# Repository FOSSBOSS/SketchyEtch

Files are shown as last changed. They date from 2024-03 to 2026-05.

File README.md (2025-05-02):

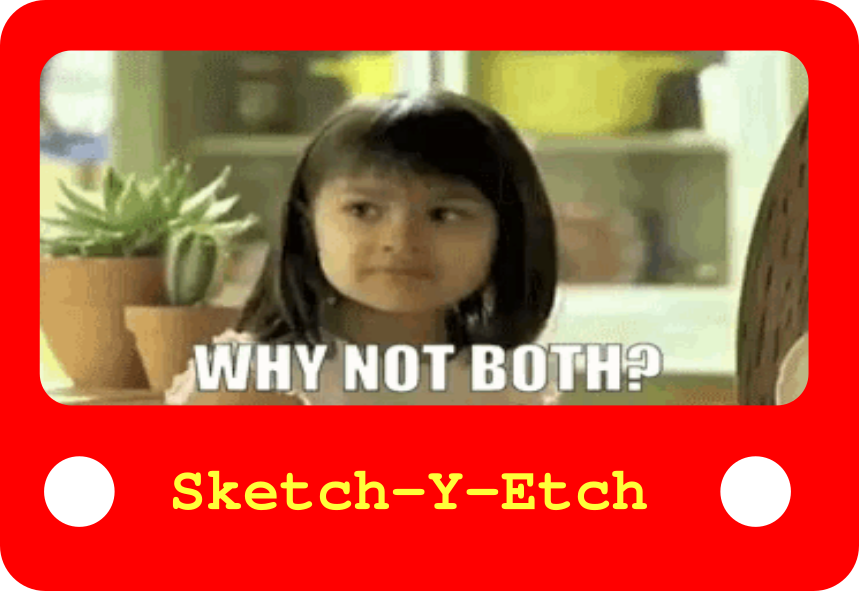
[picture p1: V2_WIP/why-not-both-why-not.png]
why not both meme asking why not both keyboard and encoders?

<br>
Sketch-Y-Etch is a retrospective etch-a-sketch-esque drawing expirience with a modern twist.<br>
The Sketch-Y-Etch project is undergoing a major revission, in a exploration of new and novel methods.<br>
This is educational project if you want it to be, and just plain fun if you just want to do some drawing.

<b>version 1:</b><br>
The project is housed in a 43 inch TV, with the addition of 2 rotary encoders, 4 buttons providing keystokes using an microcontroler.<br>
<b>Version 2:</b><br>
focuses even more on being platform agnostic, requiring only an HMDI port, or a keyboard. Linux, Mac, or windows, Sketch-Y-etch is designed to run on ANYTHING.<br>
<br>Embeding this prject in a TV is fun, but not required. The Sketch-Y-Etch project is highly flexible, and OPEN to many types of installations.<br>
<br>You want a 72" Sketch-Y-Etch? do it! Embed it into a projector with a raspberry pi? You can do it! want to just open it up and run on your PC? Not a problem.<br>
<br>We are very interested to see what you create. Need some help making your own? better documentation is on the way, and I'm here to help.<br>
If you are in the greater Bangor Maine area, feel free to come to the Bangor Makerspace to check the sketch-y-etch out in person!

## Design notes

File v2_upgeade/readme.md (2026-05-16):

Version 2 official: <br>
Upgrade Hardware: Bournes encoders, with Adafruit Sawsaw drivers<br>
<a href="https://www.adafruit.com/product/4991">https://www.adafruit.com/product/4991</a><br>

Teensy 4.0: <br>
<a href="https://www.pjrc.com/store/teensy40.html">https://www.pjrc.com/store/teensy40.html</a><br>

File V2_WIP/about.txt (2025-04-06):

Givent the overwhelming popularity of this prject, and my aquisition of additonal materials, and new expiramentable desgings,
this prject is going to see a version 2! Very exciting I know!

We are going to take the work from HDMI2C, and expand it to this project.
That means putting rotary encoders into the HMDI I2C bus, and processing inputs. 

Some other feature ideas:
background color change.
vectors
a GUI config file?
size and shape variants of the pen
more colours
acceleration to speed up drawing large images. 

<<<<<<< HEAD
I just realized a perk to the new encoders having memory of thier last, (present?) location. It means I can turn the scan rate way down, and keep bandwitch low. 

write a postitional reset into the reset button...

=======
 ./e2.py 
X -1, Y -1
X 0, Y 0
X 0, Y 0
X 0, Y 0
>>>>>>> e5b12baa7a86e95032f2eb649dd70b8922dff139

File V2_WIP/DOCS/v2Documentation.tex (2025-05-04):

\documentclass[]{article}
\usepackage[hidelinks]{hyperref}
\usepackage{graphicx}
%opening
\title{Building a better Sketch-Y-Etch}
\author{Sensored Hacker}

\begin{document}

\maketitle

\begin{abstract}
Initial versions of the sketch-y-etch had issues related to haphazard planing, and inconsistent use of parts. It has been two years since the initial creation filled the Bangor Makerspace with retro drawing for all, and we have heard many things about 
what makes the sketch-y-etch hard to use. Here in v2, we are going to try an fix the issues. 
\end{abstract}

\section*{ISSUES:}
\begin{itemize}
	\item \textbf{Drawing Performance:} Performance was limited by encoder issues.
	\item \textbf{Build Quality:} V1 used available parts with no specific plan for integration, negatively affecting the overall experience.
	\item \textbf{Stability:} The wobble made drawing difficult. While the Sketch-Y-Etch has never tipped over, it feels like it could—and that can be fixed.
%	\item \textbf{Portability:} Portability was never a design goal of V1 but can be improved in V2.
	\item \textbf{Documentation:} Existing documentation focused on the history and developer notes but lacked detailed build instructions.
	\item \textbf{Bill of Materials:} A BOM was non-existent in V1. Not everyone has a stockpile of miscellaneous computer parts.
\end{itemize}

\section*{Improvements}

\begin{itemize}
	\item \textbf{Improved Components:} A concerted effort was made to use higher-quality parts throughout the build.
	\item \textbf{Specialized Hardware:} A new conceptual design in v2 maintains compatibility with a wide range of hardware and platforms, while offering many new design options.
	\item \textbf{Focused Documentation:} We want you to build your own Sketch-Y-Etch! A detailed tutorial is now available to guide you through the process.
	\item \textbf{New Features:} More colors, adjustable pen size, dynamic scaling, and additional enhancements.
	\item \textbf{Bill of Materials:} All required parts can be easily acquired, with a total estimated cost of about \$50.
\end{itemize}

\section*{Recommended Software}

The only essential software requirement for the Sketch-Y-Etch is a working installation of Python 3:
\begin{itemize}
	\item Python 3: \url{https://www.python.org}
\end{itemize}
You will also need the \texttt{numpy} and \texttt{smbus2} libraries, which can be installed with:

\begin{verbatim}
	pip install numpy smbus2
\end{verbatim}

\section*{Download the Code}
Download the source repository for the Sketch-Y-Etch project, available at:  
\url{https://github.com/FOSSBOSS/SketchyEtch}

Once you have the repository, extract it if necessary, and navigate to the \texttt{v2\_WIP} folder.  
In your IDE of choice, try running \texttt{SketchyV2\_WIP.py}.

If you encounter import errors, you may be missing required libraries, or your Python 3 path may be incorrect.

\begin{figure}[ht]
	\centering
	
	\caption{Missing \texttt{smbus2} library error example.}
	\label{fig:missing_smbus2}
\end{figure}

Sketch-Y-Etch app keys:
\begin{itemize}
	\item Arrow keys: Left Right, Up, Down, moves the pen respectively.
	\item c, clears the screen.
	\item g, get a new color. Press it until you find what you want.
	\item l, lift pen. press again to set pen down.
	\item s, save your work. 
	\item q, quit, close the program.
%	\item more buttons on the way  
\end{itemize}

If you are choosing to use the Sketch-Y-Etch software for fun drawing, without building a whole thematic retro electronics installation, then you can stop reading now. 
Else: continue.

\section*{Let's Build It!}

To begin building your Sketch-Y-Etch, you will need a set of materials and tools.  
The Bangor Makerspace offers complete kits for purchase if you are interested, or you can source your own components independently.

\subsection*{Required Tools}

Basic tools required for assembly include:
\begin{itemize}
	\item Screwdrivers
	\item 3D printer
	\item Wire cutters
	\item Soldering station
	\item Drill and drill bits
	\item Personal protective equipment (PPE)
\end{itemize}

\subsection*{Electronic Components}

The Bangor Makerspace developed the HDMI-TAP specifically for this project. While its use is highly recommended for simplicity and reliability, it is also possible to build a compatible alternative at relatively low cost.\\

This project utilizes Qwiic connectors for inter-device communication over I\textsuperscript{2}C.  
A common practice in electronics is to color-code wires according to their function. Although wire insulation color does not affect circuit operation, following a standard color convention greatly simplifies visual inspection and troubleshooting.

In this project, the following color scheme is used:

\begin{itemize}
	\item \textbf{Red:} +5VDC (power)
	\item \textbf{Black:} Ground (common)
	\item \textbf{Blue:} SDA (I\textsuperscript{2}C data line)
	\item \textbf{Yellow:} SCL (I\textsuperscript{2}C clock line)
\end{itemize}

As a mnemonic, you can remember that \textit{yellow} (like the sun on a sundial) represents the clock signal.

This color convention matches the standards used by Adafruit STEMMA QT and SparkFun Qwiic connect systems, utilized in this project.

\subsection*{Bill of Materials}

\begin{center}
	\begin{tabular}{|l|l|c|l|}
		\hline
		\textbf{Item} & \textbf{Part Number / Name} & \textbf{Qty} & \textbf{Notes} \\
		\hline
		Rotary Encoder & Adafruit Seesaw Encoder   & 4 & I2C, with built-in pull ups \\
		Display        & HDMI Monitor              & 1 & Any 1080p-capable screen \\
		Cables         & Assorted Qwiic Wires      & 5 & Male-male and male-female \\
		Knobs          & Custom 3D-Printed Knobs   & 1 & STL files available \\
		Computer       & Any with HDMI Output      & 1 & Laptop, desktop, or SBC \\
		HDMI-TAP       & v2 w/qwiic connects	   & 1 &  easy access HDMI i2c bus.\\
		Optional	   & I2C bus splitter	       & 1 & can make routing easier.\\
		
		\hline
	\end{tabular}
\end{center}

\section*{Install Hardware}
% dont forget to write about the ADC!
The Sketch-Y-Etch application will run on Any platform where python3 is installed. Windows, Mac, or Linux, Arm, i686, x86\_64 .... it can run on any standard PC hardware. If you just want to draw, and don't care about making it look cool, can skip this step, and the steps below.

\section*{Embrace Complexity}

This project has many possible configurations. Here are two basic setups you might consider:

\begin{enumerate}
	\item Connect a computer to the Sketch-Y-Etch, then to a display screen.
	\item Connect a laptop's HDMI output directly to the Sketch-Y-Etch.
\end{enumerate}

Many possibilities and functionalities exist at this stage. The zeitgeist of this project is to embrace experimentation, and creativity with flexibility. Take some time to consider how you want to configure your Sketch-Y-Etch.

While video pass-through is an option, if you have multiple display outputs, you may route your controls in various ways. You might choose to embed the Sketch-Y-Etch into a TV, build a standalone control panel, make multiple controllers on one computer, use a projector, or simply run the app on your computer without specialized electronics.

Is HDMI strictly required? Not necessarily. HDMI is modern and widely available, but it is not the only option. Other video or data interfaces could be adapted with additional development effort. Adaptions may change the path of these instructions, which should conceptually work regardless of your desired implementations. I am however not going to write a new tutorial for every conceivable build path, or video technology in existence. 

Please keep in mind: this project remains experimental. It is not intended as a polished, professional consumer product.  
While it is feasible to create a more plug-and-play experience, the practical setup will depend heavily on the specific hardware you have available.
This flexibility can be confusing, the key is to clearly define what you want to build before you start building it.

\subsection*{Optional Steps}

These steps are not strictly required but are highly recommended to simplify testing and setup. 3D printing the knobs, and experimental build platform may take approximately an hour of printing, depending on your printer. Print 4 knobs, and 1 table. Please note that the current knob.stl file is sized for the encoders used in this project, if you are using some other unspecified component you may need to adjust the models to meet your specific needs. 

\begin{enumerate}
	\item 3D print the \texttt{table.scad} build platform and install your devices onto it.
	\item Drill or melt holes into the table  to match your layout preferences. 
	\item Install the knobs by pushing them on to the encoder shafts. Using alternate knobs is also acceptable, we're just trying to make the encoders easy to use.
	\item Test and verify all hardware and software functionality using the build platform before embedding the electronics into a TV.
	\item If embedding a computer into an other device, its a good idea to have an easy means of access. Ssh, wireless keyboard, or leave the covers off until you are sure everything is running properly. 
\end{enumerate}

\section*{Wiring}
Assuming you are following along with building the test platform first for testing, and your 4 rotary encoders are now installed, flip the table to view the encoders for wiring.
The encoders have directionality, which may be counter intuitive, and limited a specific models. There is an input side, and an output side. If looking at the underside of the encoder, with the LED at the top, or away from you, the input port is on the left, and the output Qwiic connect port is on the right. You may opt to label the ports I for input and O for output. When connecting the encoders, you will connect from the output of the first encoder to the input of the next encoder in line. 
\begin{figure}[ht]
	\centering
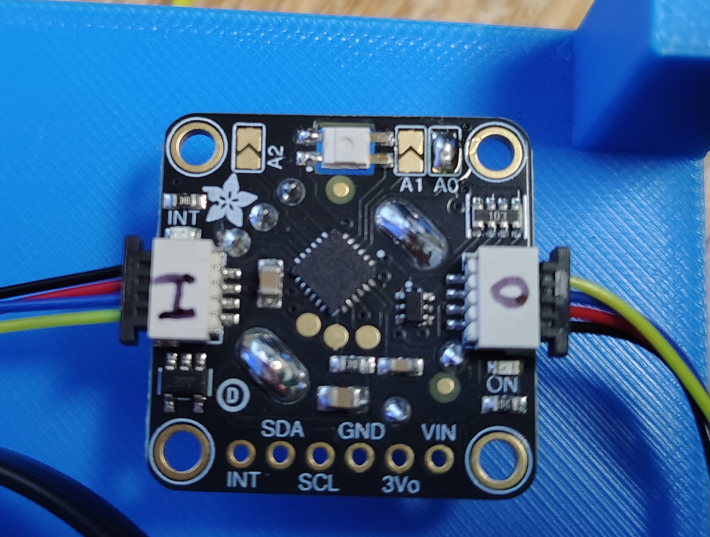
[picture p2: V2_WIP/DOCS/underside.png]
	
	%	\caption{flipside \texttt{encoder underside} }
	\label{fig:encoder_underside}
\end{figure}
Here, you can observe the exposed A0, A1, and A2 pads. These pads control the I\textsuperscript{2}C addresses your encoders use to communicate on the bus. 
By default, all pads are disconnected, which is how the encoders are shipped from the factory. The default I\textsuperscript{2}C address is \texttt{0x36}.

By bridging these pads with solder, you manually set the device's address. You can attach your encoders in any order; however, each encoder must have a unique address. Up to eight address combinations are possible.
Please note that whichever addresses you assign must be configured correctly in the software to ensure that each encoder performs its designated function.
 
\begin{figure}[ht]
	\centering
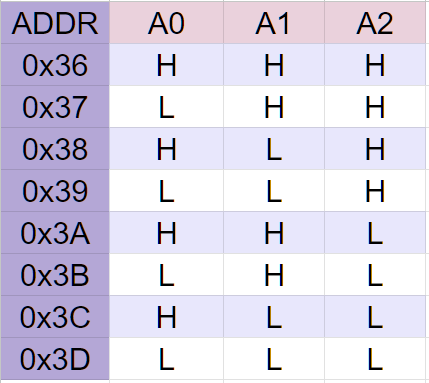
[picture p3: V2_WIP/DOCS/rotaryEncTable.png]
	
	\caption{Encoder addresses \texttt{Empty pad is high by default} }
	\label{fig:address asignments}
	\end{figure}

Once you have assigned your 4 distinct addresses by soldering, record those addresses, and their respective functions per your board layout. You will need this information when you go to adapt the SketchyEtch.py code to your specific installation.
The findbus function will search for your 4 encoders, when the program loads. If you set your encoder addresses to something other than 0x36,0x37,0x38,0x39, you will need to change the known\_addrs values to reflect the values you have set. 
The specific encoder addresses also control which encoder controls what Sketch-Y-Etch function. If in the code the findbus function does not find your encoders, the Sketch-Y-Etch program will default to using a keyboard for drawing. Depending on your project construction, this may be a problem. If your computer is embedded into your tv, or projector, and attaching a keyboard is difficult, then be sure to configure the known\_addrs before hand.  The sketch-y-etch program does not continuously scan for known addresses, rather is only scans during initialization. 

% probably change this in code, to be one set of variable assignments.

\section*{More wiring} I used an ADS115 Analog to Digital Converter (ADC) to add 4 buttons to this project. Its wild overkill for the project, but Im going to build other projects with that part, so I wanted to figure out the logic for it anyway.
As in using it was educational for me. For you, this part is cheap, and readily available. The logic of using the ADC is also flexible, and exceedingly simple once you have the code to listen to the device set up. If a button normally tied high, goes low, perform a function. 
How does that work? I used 4, 10K ohm resistors tied to +5VDC to the "A" inputs of the ADC, and the normally open switch tied to ground. when the button is pressed, the voltage on the input goes low. This is not a short circuit, because of the resistor. So then our code sees a low value on the channel where the button was pressed, and we respond accordingly by calling a function.  

\section*{Inspect}
Inspection is an important step in every electronics project. Mistakes happen, the world is a distracting place, and the fragility of human existence can lead to some unfortunate side effect. Your electronics projects do not need to suffer from this. Look for loose wires, stray strands of wire poking out of terminals, connectors ajar,  messy incoherent wiring... if you can spot problems before they start, it will be safer, and less confusing later. If everything on your test rig looks good, try plugging it in.\\ projects rarely work perfectly the first time around, even with expertly drafted and bespoke instructions. 

Plug your test rig in. Fire? unplug it.\\No fire? no smells? \\ Great!! you have passed the first step of electronics tinkering!
Did your externally attach monitor resume video playback? Did the power lights on the encoders illuminate?

\begin{figure}[ht]
	\centering
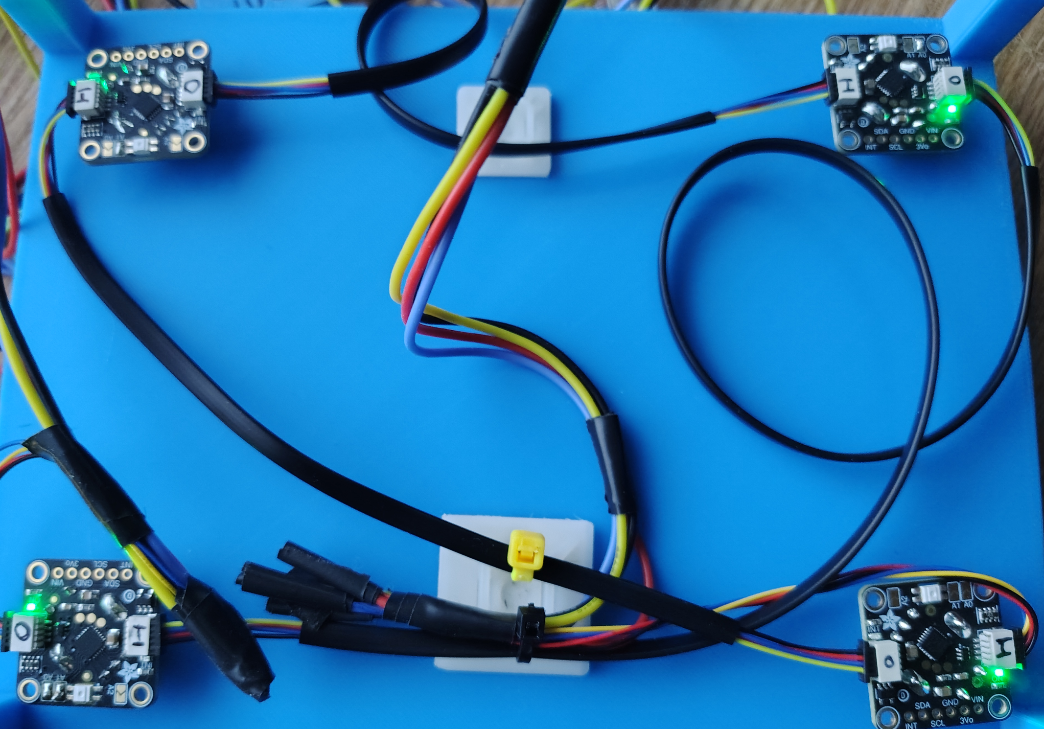
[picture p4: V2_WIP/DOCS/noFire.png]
	
	\caption{Lights on! \texttt{no fire!} }
	\label{fig:looks_good}
\end{figure}

If every thing seems to be working, then lets proceed. 
If you start to smell something, or your computer begins to behave erratically, I would suspect the newly attached experimental electronics project, and unplug it as best practice. 

\section*{Test Hardware}

\section*{Adapt the code}

\section*{Play Time!}

\section*{Troubleshooting}
\subsection{No video:} If you ran the solitary signal ground though the qwiic connectors, a disconnect on any of the encoders could prevent video pass thru.\\Check your sensors, and encoders. The kit version should not be as susceptible to this issue.
The i2c bus is not strictly required by the HDMI video connection, its use is in identifying connected devices. The signal ground however is required for the video signals. You could add a ground cable, or just check your wiring. 
\subsection{Flashy Flashy:} flickering, or stuttering can occur when the Hot Plug Detect is wired straight through, and or not tied to the +5VDC line. The GPU, or video device is basically always searching for, and confirming the eeprom of the attached screen, TV, projector etc. When the detection is confirmed, the device sends a signal in the form of +5VDC to the video driver verifying the connection. If the HPD passes straight through, your screen will flicker at the rate of the polling. Tying the HPD high prevents the flicker, but does not stop the polling. Again, check your wiring.
\subsection{screen tearing:} Depending on the size of your screen and the computer you use to supply video, you could run out of video memory. This is exceedingly close on screens larger than 52 inches on devices like the raspberry pi which do not have a lot of video memory.
\subsection{Video output issues:} try removing the pass through. custom connections may be wired incorrectly. \\

\section*{Contact}
\begin{enumerate}
\item You love this project, and want to contribute!
\item You have commentary about this document, project, code and want further detail.
\item Complaints. This project sucks! Believe me, I KNOW. With a wanton disregard for more performant hardware, and methods I bravely undertook this project despite the stern remarks from veteran Electrical Engineers and programmers alike. Don't tell me how to have fun!
\end{enumerate}

\section*{Nobody asked:}
\subsection{I2C bus topologies:}
Venturing into the realm of TMI, learning about I2C bus topologies can give you insight into various ways you can build future projects. 

\subsection{i2c Sucks!} Well, yeah, kinda.
\begin{itemize}
	\item \textbf{Very Slow}: Typical speeds are \textbf{100 kHz}, to maybe \textbf{400 kHz}
	\item \textbf{Short Distance}: Designed for communication across a single PCB or a few inches of wire. Beyond $\sim$1 meter, signal integrity issues like reflections, capacitance, and noise become problematic.
	\item \textbf{Shared Bus = Traffic Jams}: All devices share the same two wires (SDA and SCL). A slow or malfunctioning device can stall the entire bus.
	\item \textbf{Limited Error Handling}: Only basic ACK/NACK mechanisms are provided; no robust error correction or retry protocols.
	\item \textbf{Limited Bandwidth}: As a shared bus, more devices mean reduced effective performance.
	\item \textbf{Requires Pull-Up Resistors}: Since I\textsuperscript{2}C uses an open-drain configuration, pull-up resistors are needed, leading to:
	\begin{itemize}
		\item Slow signal rise times
		\item Higher active power consumption
		\item Sensitivity to wiring quality and length
	\end{itemize}
\end{itemize} 
But its also easy to implement, as I hope this project shows, and devices using it are prevalent. 

\section{Aversions to hardware hacking:} yes we took a devices and modified its normal operation to garner our own distinct operation. I've heard all manner or cries about the feasibility of interrupting the I2C bus on a video port. I have news for you: while the typical operation is to use video output devices to communicate with internal memory of screens, and TVs and projectors, a wide array of devices also interrupt the I2C bus to garner their own functionality. So one, this operation is not all so outlandish. Further still, any given I2C buss can communicate with up to 127 devices, and the typical utilization is just using 1. The same folks screaming about interrupting the i2c bus have no problem with a 20 foot long HDMI cable which subjects the circuit to the same sorts of noises and losses.  

\subsection*{Helpful Tools}

The Sketch-Y-Etch was developed primarily on Linux using Python 3 alongside a variety of additional software tools:

\begin{itemize}
	\item OpenSCAD ( for 3D design ): \url{https://openscad.org}
	\item Geany ( lightweight code editor ): \url{https://www.geany.org}
	\item KiCad ( PCB design and schematic capture ): \url{https://www.kicad.org}
	\item i2c-tools ( I\textsuperscript{2}C communication utilities ): \url{https://archive.kernel.org/oldwiki/i2c.wiki.kernel.org/index.php/I2C_Tools.html}
\end{itemize}

While the design should, in principle, work on any operating system, platform-specific nuances have not been extensively tested.  
The tools listed above reflect the preferences of the original developer. Although not strictly required, they are highly recommended for a smoother and more educational development experience.

\section*{References}

\begin{itemize}
	\item Turtle Graphics API (Python Standard Library): \url{https://docs.python.org/3/library/turtle.html}
	\item Smbus2 (Python I\textsuperscript{2}C library) : \url{https://pypi.org/project/smbus2}
	\item I\textsuperscript{2}C Implementation Guide (SparkFun): \url{https://learn.sparkfun.com/tutorials/i2c/all}
	\item Adafruit encoder pin outs \url{https://learn.adafruit.com/adafruit-i2c-qt-rotary-encoder/pinouts}
	\item Adafruit Seesaw Library: \url{https://github.com/adafruit/Adafruit_Seesaw}
	\item Component Data sheets: Included in this repository.
	\item The Book of I\textsuperscript{2}C by Randal Hyde \url{https://nostarch.com/book-i%C2%B2c}
\end{itemize}

All references are provided for educational purposes. They are not required to complete the project but may offer valuable background information.

\section*{burgeons:}
A fun side project is to modify your TV, projector, or screen to report its identity as a Sketch-Y-Etch, or whatever you want I suppose. But this is a topic for a different discussion.  

\end{document}

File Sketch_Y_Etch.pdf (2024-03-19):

# Sketch-Y-Etch a retrospective drawing experience for the masses

SensoredHacker0 @ The Bangor Makerspace

March 19, 2024

Abstract

The Sketch-Y-Etch is a pseudo clone of the classic Etch-A-Sketch with a modern twist. Features include similar Cartesian drawing using knobs, with the addition of being able to change colors, lift the pen, erase segments, Erasing without shaking, saving files, and its huge. Written in python, utilizing standard hardware, and some open source projects, lets explore the Sketch-Y-Etch, and how you can create your very own.

## History

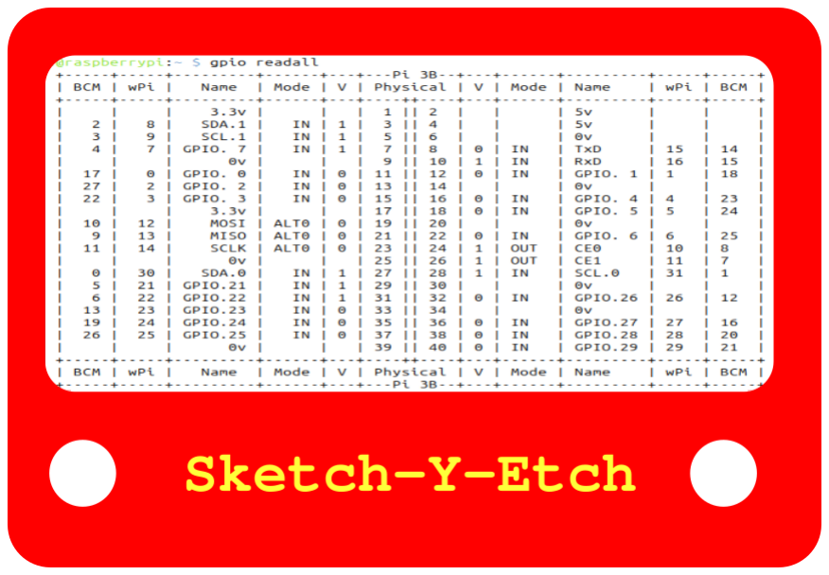
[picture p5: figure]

The Sketch-Y-Etch is thematically based on the classic Etch-A-Sketch. The Etch-A-Sketch is a mechanical drawing toy invented in 1960 by Andr´e Cassagnes of France and subsequently manufactured by the Ohio Art Company. Similar to the original, knobs are used to control x,y axis drawing. Sketch-Y-Etch however is a computerized project, and similarities end there.

## Programming:

The Sketch-Y-Etch program uses a micro controller acting as a keyboard, and Python for graphics. The Python3 code listens for key commands, and the micro controller provides them via IO. A standard keyboard would also work. Source Code is available at:
https://github.com/FOSSBOSS/SketchyEtch

1

## Software Resources Used:

OpenScad to 3D model the Knobs.
The micro controller interface was coded in Arduino IDE using C++. The drawing program is in Python3, using the turtle library. Unclutter is used to hide the mouse cursor.
Nginx is used to provide a web interface to retrieve saved files.

## Construction:

The Sketch-Y-Etch project is designed to run on standard computer hardware. Making A version using buttons and knobs is entirely optional, though in our opinion, much cooler.

Material needs: Two rotary encoders, four buttons. a micro controller capable of acting as a keyboard, a computer of some sort, and a TV.

This project utilizes a raspberry Pi 3b+, and a Samsung ln26A330j1 30 inch TV. Any TV, and computer of your choice should work. This model TV, has wide bevels, and lots of internal space where hardware can be embedded. If you can not get a TV with space to embed various additional electronics, as many modern TVs do not have bevels, you could create a control panel, or make a box to contain your additional electronics.

## Tribulations of the build:

This project went through many revisions. The initial version had a 6 by 8 foot screen and stood nearly 10 feet tall. It was also heavy, and impossible to move.

Raspberry Pies have GPIO.. why did we not use that for IO? Several versions were created to utilize Raspberry PI GPIO. Testing revealed latency problems, that we did not want to deal with. Also, utilizing standard hardware maximizes the number of devices, and subsequent variants which can be built.

The second revision implemented the idea of using keystrokes to control navigation. This allowed us to share the Sketch-Y-Etch concept with other developers interested in the project, without forcing them to have a Raspberry PI, and custom electronics.

## Operation:

Usage should be intuitively similar to using an Etch-A-Sketch. Turn knobs, make pictures. Cycle through a set of colors with a push button. Momentarily stop drawing, and move your marker with the lift button. Erase it all with the

2

erase button. Save an image using the save button, and for display purposes, use the demo switch to run a demonstration mode which showcases various drawings, documentation, and other info.

To use the Sketch-Y-Etch drawing program with a keyboard, use these left and right arrow keys to navigate on the +/-X plane. Up and Down arrow keys navigate the +/- Y plane. Press g to change the color. Pressing g again will shift to the next color in the list. pressing g until the white color is selected enable the erase function, as the background is white. press l to toggle the lift pen function. Lifting the pen allows the cursor to be moved, without drawing. Press c to clear the screen. The cursor will reset to the center position, and erase everything which has been drawn. Press s to save the file, and d to enable demo mode.

## Annex of caveats and deviations:

The rotary encoders in use with the Sketch-Y-Etch were chosen based on availability. The encoders feature detents, which in this application, have a tendency to cause the encoder to shift forward, or backward when a user stops on the ridge of a detent. Unexpected drawing may occur. Perhaps we could add something in code to compensate this action, or maybe next time we’ll use a more apt encoder type.
Latency is built into the sensor IO board, to prevent key spamming. Additional latency is added to the save key, to deter excessive saving of images. The Python script may require modification to save at an appropriate location.

## Annex of variations:

The Sketch-Y-Etch was developed on a variety of Raspberry Pies, and an assortment of TVs & monitors. We chose a Raspberry PI 3b+ as a minimum operational specification. Should you build your own version, and encounter glitches, or various nuances, The Bangor Makerspace is certainly interested in offering assistance. The Sketch-Y-Etch was developed 100% on Linux, and has no other platform testing to date. Given how the Sketch-Y-Etch program operates, we see no specific reason it can not be adapted to any other platform; we simply haven’t tested this.

## Conclusion

The Sketch-Y-Etch is an open source project developed at the Bangor Makerspace. Our intent is to create something fun, and easy to use for everyone to enjoy.

3

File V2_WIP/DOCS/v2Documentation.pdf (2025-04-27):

# Building a better Sketch-Y-Etch

Sensored Hacker

April 27, 2025

Abstract
Initial versions of the sketch-y-etch had issues related to haphazard planing, and inconsistent use of parts. It has been two years since the initial creation filled the Bangor Makerspace with retro drawing for all, and we have heard many things about what makes the sketch-y-etch hard to use. Here in v2, we are going to try an fix the issues.

## ISSUES:

- Drawing Performance: Performance was limited by encoder issues.
- Build Quality: V1 used available parts with no specific plan for integration, negatively affecting the overall experience.
- Stability: The wobble made drawing difficult. While the Sketch-Y-Etch has never tipped over, it feels like it could—and that can be fixed.
- Portability: Portability was never a design goal of V1 but can be improved in V2.
- Documentation: Existing documentation focused on the history and developer notes but lacked detailed build instructions.
- Bill of Materials: A BOM was non-existent in V1. Not everyone has a stockpile of miscellaneous computer parts.

## Improvements

- Improved Components: A concerted effort was made to use higherquality parts throughout the build.
- Specialized Hardware: A new conceptual design in v2 maintains compatibility with a wide range of hardware and platforms, while offering many new design options.
- Focused Documentation: We want you to build your own Sketch-Y-Etch! A detailed tutorial is now available to guide you through the process.

1

- New Features: More colors, adjustable pen size, dynamic scaling, and additional enhancements.
- Bill of Materials: All required parts can be easily acquired, with a total estimated cost of about $50.

## Let’s Build It!

To begin building your Sketch-Y-Etch, you will need a set of materials and tools. The Bangor Makerspace offers complete kits for purchase if you are interested, or you can source your own components independently.

Required Tools

Basic tools required for assembly include:
- Screwdrivers
- 3D printer
- Wire cutters
- Soldering station
- Drill and drill bits
- Personal protective equipment (PPE)

Electronic Components

The Bangor Makerspace developed the HDMI-TAP specifically for this project. While its use is highly recommended for simplicity and reliability, it is also possible to build a compatible alternative at relatively low cost.
This project utilizes Qwiic connectors for inter-device communication over I

2C. A common practice in electronics is to color-code wires according to their function. Although wire insulation color does not affect circuit operation, following a standard color convention greatly simplifies visual inspection and troubleshooting.
In this project, the following color scheme is used:
- Red: +5VDC (power)
- Black: Ground (common)
- Blue: SDA (I²C data line)
- Yellow: SCL (I²C clock line)

As a mnemonic, you can remember that yellow (like a sundial) represents the clock signal.
This color convention matches the standards used by Adafruit STEMMA QT and SparkFun Qwiic connect systems, utilized in this project.

2

Bill of Materials

Item | Part Number / Name | Qty | Notes
Rotary Encoder Display Cables Knobs Computer HDMI-TAP | Adafruit Seesaw Encoder HDMI Monitor Assorted Qwiic Wires Custom 3D-Printed Knobs Any with HDMI Output v2 w/qwiic connects | 4 1 5 1 1 1 | I2C, with built-in pullups Any 1080p-capable screen Male-male and male-female STL files available Laptop, desktop, or SBC easy access HDMI i2c bus.

Optional Steps

These steps are not strictly required but are highly recommended to simplify testing and setup.

1. 3D print the table.scad build platform and install your devices onto it.
2. Test and verify all hardware and software functionality using the build platform before embedding the electronics into a TV.

## Recommended Software

The only essential software requirement for the Sketch-Y-Etch is a working installation of Python 3:

- Python 3: https://www.python.org

Helpful Tools

The Sketch-Y-Etch was developed primarily on Linux using Python 3 alongside a variety of additional software tools:

- OpenSCAD (for 3D design): https://openscad.org
- Geany (lightweight code editor): https://www.geany.org
- KiCad (PCB design and schematic capture): https://www.kicad.org
- i2c-tools (I²C communication utilities): https://archive.kernel.org/oldwiki/i2c.wiki.kernel.org/index.php/I2C_Tools.html (https://archive.kernel.org/oldwiki/i2c.wiki.kernel.org/index.php/I2C_Tools.html)

While the design should, in principle, work on any operating system, platformspecific nuances have not been extensively tested. The tools listed above reflect the preferences of the original developer. Although not strictly required, they are highly recommended for a smoother and more educational development experience.

3

## References

- Turtle Graphics API (Python Standard Library): https://docs.python.org/3/library/turtle.html (https://docs.python.org/3/library/turtle.html)
- I
2C Implementation Guide (SparkFun): https://learn.sparkfun.com/tutorials/i2c/all (https://learn.sparkfun.com/tutorials/i2c/all)
- Adafruit Seesaw Library: https://github.com/adafruit/Adafruit_Seesaw
- Component Datasheets: Included in this repository.

All references are provided for educational purposes. They are not required to complete the project but may offer valuable background information.

4

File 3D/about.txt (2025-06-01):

ok it can work, so now im figuring how to make it work better.
I realized my code sucks when I took the controler appart, and re-assembled it. annoyance ensuded.
Openscad is pretty jank, but its the simplest avenue I know of.

probably just stick to 45 degree x,y, and make E#2 button toggle rotate vs zoom.
oh and we're going to try making a clear function to zero the encoders, delete all the objects, and reset all the variables. 
oh and the is a fair number of colors in openscad. no idea if that integrates with a printer easily.
'''
viewer configs (simple) 45s might be better

$vpr = [0, 0, 0];       // Looking along -Z (default view)
$vpr = [90, 0, 0];      // Looking along -Y (Y comes toward viewer)
$vpr = [0, 90, 0];      // Looking along -X (X comes toward viewer)
$vpr = [0, 0, 90];      // Looking along -Z, but rotated clockwise (X is left)
$vpr = [0, 90, 90];     // Looking along -X, rotated CW (Z is down)
$vpr = [90, 0, 90];     // Looking along -Y, rotated CW (X is right)
$vpr = [90, 90, 0];     // Looking diagonally between -X and -Y
$vpr = [90, 90, 90];    // Looking along -X, Z is down

$vpr = [-90, 0, 0];     // Looking along +Y (Y comes toward viewer)
$vpr = [0, -90, 0];     // Looking along +X (X comes toward viewer)
$vpr = [0, 0, -90];     // Looking along -Z, rotated counter-clockwise (X is right)
$vpr = [0, -90, -90];   // Looking along +X, rotated CCW (Z is down)
$vpr = [-90, 0, -90];   // Looking along +Y, rotated CCW (X is left)
$vpr = [-90, -90, 0];   // Looking diagonally between +X and +Y
$vpr = [-90, -90, -90]; // Looking along +X, Z is down

$vpr = [0, -90, 90];    // Looking along +X, rotated CW (Z is down)
$vpr = [90, 0, -90];    // Looking along -Y, rotated CCW (X is left)
$vpr = [-90, 90, 0];    // Looking diagonally between -X and +Y
$vpr = [90, -90, -90];  // Looking along +X, Z is down

so thats a bunch of views. then there is $vpd, a depth type variable.
well set vpd to something like what is drawn +N.

'''

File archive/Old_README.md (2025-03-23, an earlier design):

Sketch-Y-Etch is a retrospective etch-a-sketch-esque drawing expirience with a modern twist.
The project is housed in a 43 inch TV, with the addition of 2 rotary encoders, 4 buttons and 1 switch.
Use the switch to enter demo mode, where your propaganda can be displayed. 
Button features include: Save, penup / pendown, colour change, and erase.
Rotary encoders are used to perform XY cordinate based drawing. 

Built on a Raspberry Pi 3B+ using a Teensy 4.1 to gernated keyboard IO. 

Here are some documentation resources I found helpful:
Turtle Graphics API: <br>
https://docs.python.org/3/library/turtle.html

How to Autostart Programs in Raspberry Pi OS:

https://www.instructables.com/Autostart-a-Program-When-Raspberry-Pi-Boots-Newbie/

To simply have the program run on boot (on a Pi):

sudo apt install lxsession-default-apps

Unclutter was used to hide the mouse. 

This project should work on any OS, using a keyboard, or sensor IO.
Only tested on linux though. Good Luck!

If you have seen this project live, in person, and wish to fork, or recreate it,
./fsTurt.py is the python script you care about.

The development of this project took a few itterations to get something working reliably, 
but the investigation of the various other methods are kept here in.
Why are things named the way they are? lol idk, made sense at the time.

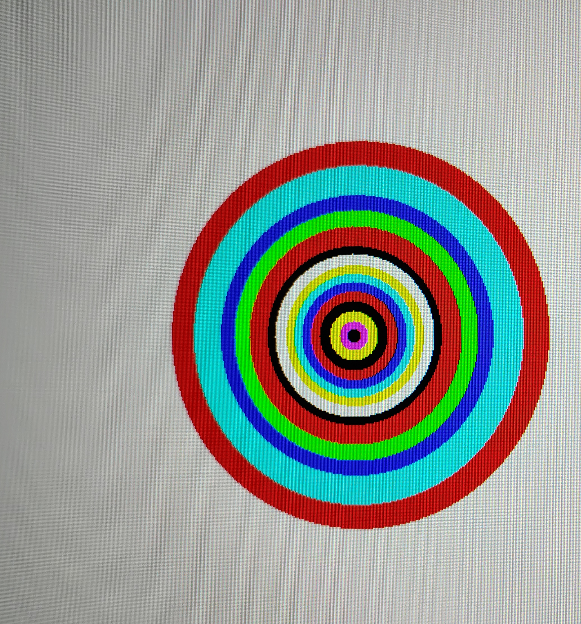
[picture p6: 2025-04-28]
V2_WIP/images/circles.png

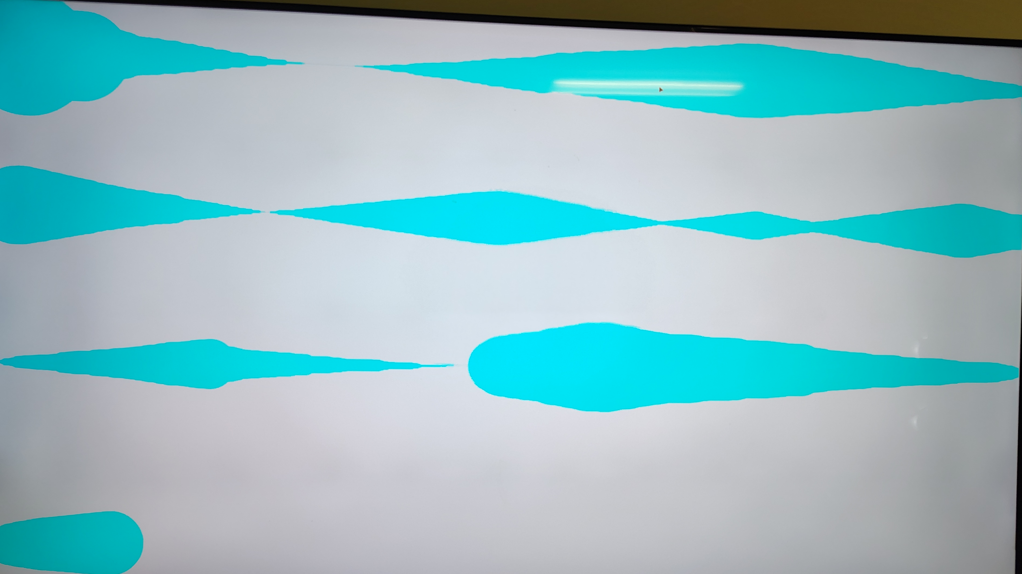
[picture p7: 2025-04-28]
V2_WIP/images/cascade.png

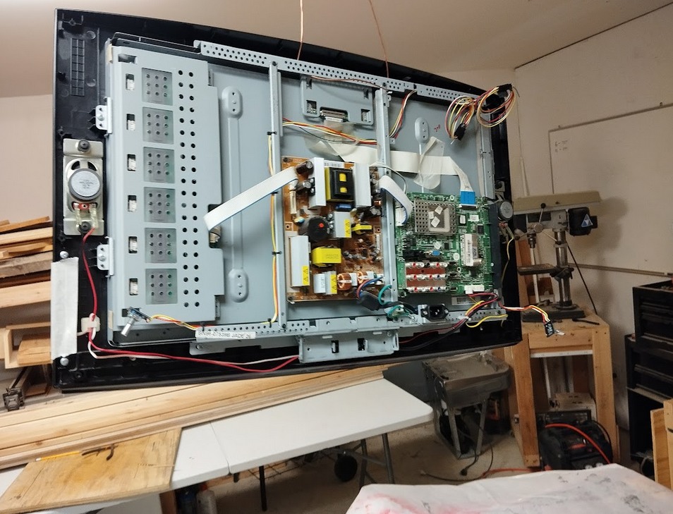
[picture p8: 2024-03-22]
v1_projectPics/hung_to_protect.jpg

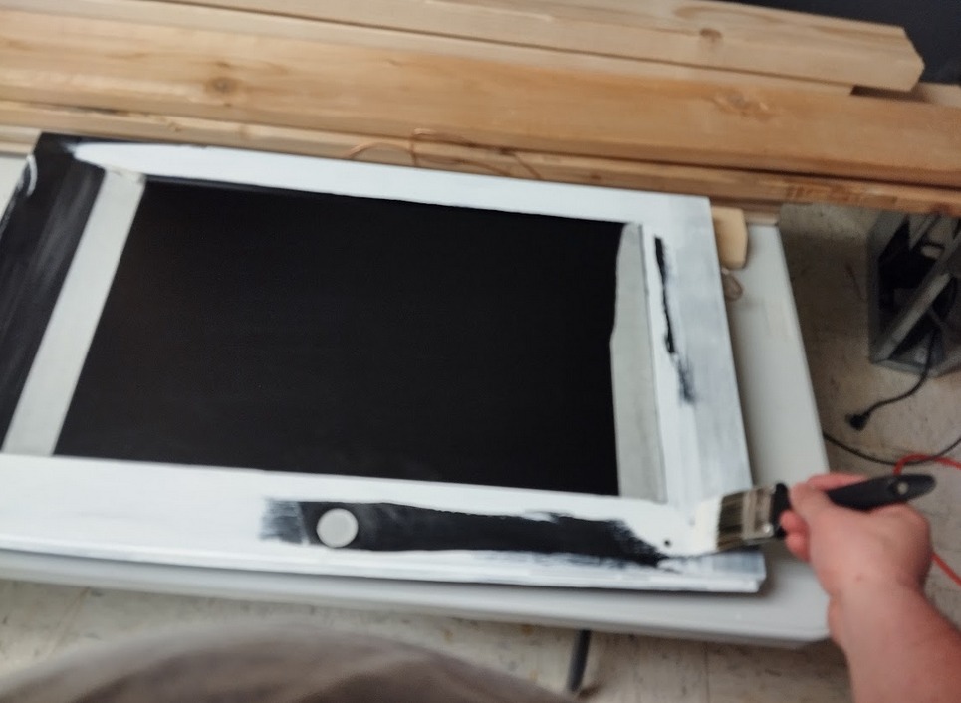
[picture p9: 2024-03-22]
v1_projectPics/prime.jpg

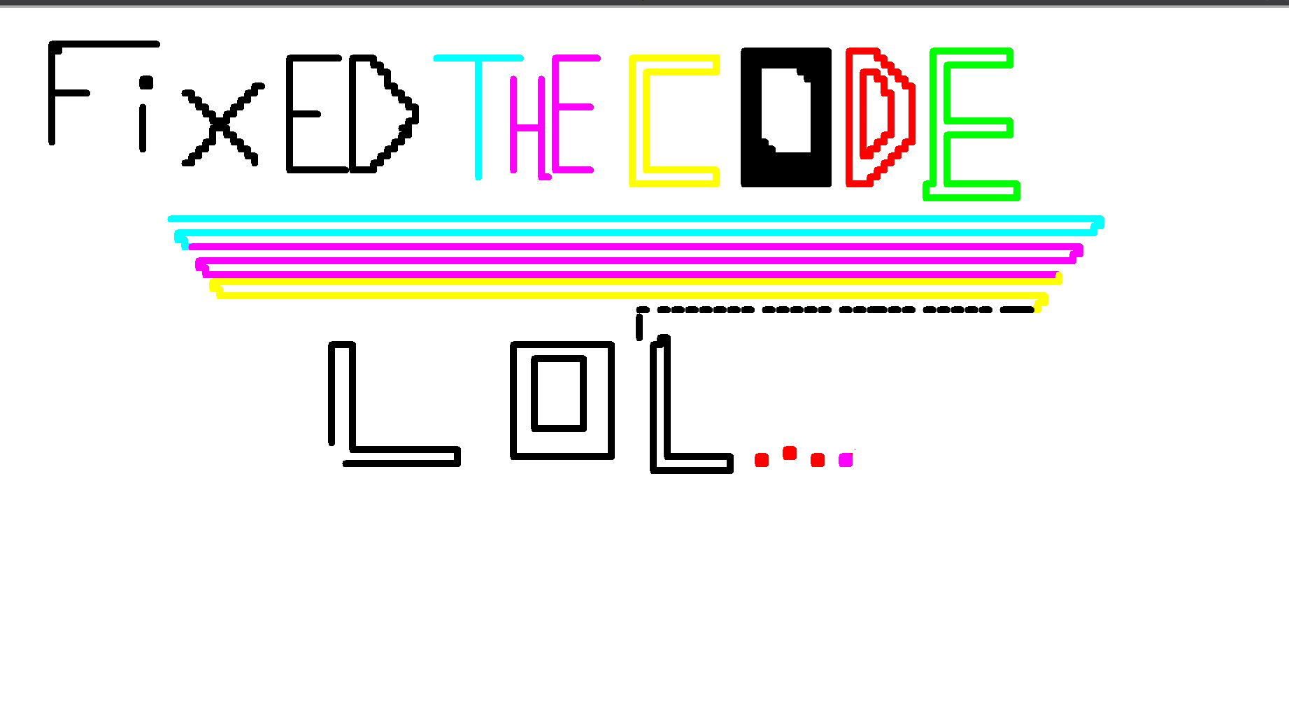
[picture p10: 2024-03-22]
v1_projectPics/play2.png

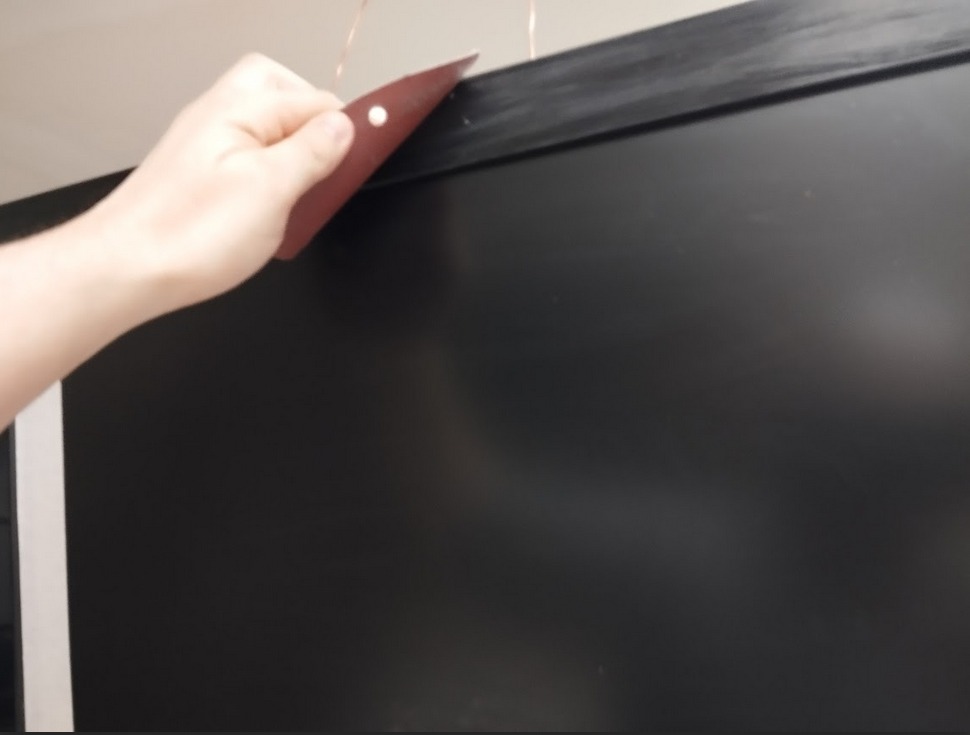
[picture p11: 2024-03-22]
v1_projectPics/sanding.jpg

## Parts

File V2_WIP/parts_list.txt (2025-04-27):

encoder: (4x)
https://www.adafruit.com/product/5880

hdmi breakout: (2x)
https://www.adafruit.com/product/3121

cables:(5x)**
https://www.adafruit.com/product/4401

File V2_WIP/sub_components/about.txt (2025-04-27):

Givent the overwhelming popularity of this prject, and my aquisition of additonal materials, and new expiramentable desgings,
this prject is going to see a version 2! Very exciting I know!

We are going to take the work from HDMI2C, and expand it to this project.
That means putting rotary encoders into the HMDI I2C bus, and processing inputs. 

Some other feature ideas:
More colors!
change pen size
dynamic acceleration to speed up drawing large images. 
new hardware implementation, that remains cross platform compatatble, and distro agnostic.

<<<<<<< HEAD
I just realized a perk to the new encoders having memory of thier last, (present?) location!
It means I can turn the scan rate way down, and keep bandwitch low, while not needing
to mess with IRQs and counters. 

=======
 ./e2.py 
X -1, Y -1
X 0, Y 0
X 0, Y 0
X 0, Y 0

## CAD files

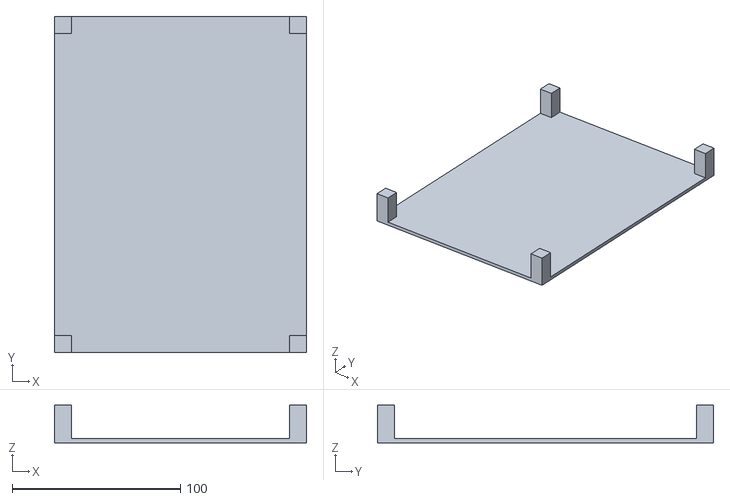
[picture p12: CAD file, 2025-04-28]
V2_WIP/3D_prints/table.stl
150.0 x 200.0 x 22.5

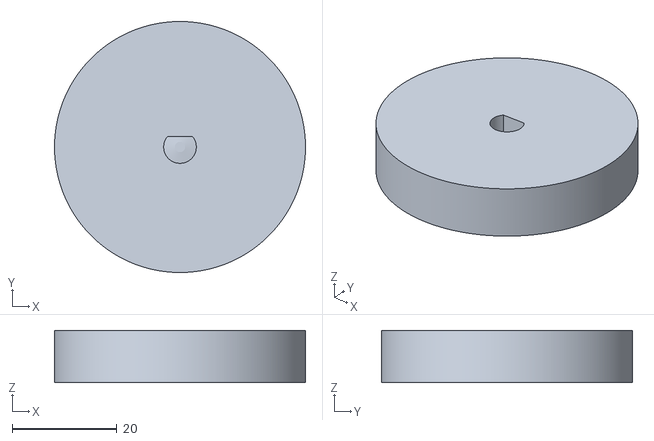
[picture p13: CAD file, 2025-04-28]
V2_WIP/3D_prints/knob.stl
48.0 x 48.0 x 10.0

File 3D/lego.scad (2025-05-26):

w=8;
h=9.6;

module lego_brick(studs=4){
    $fn = 80;
    width = 8 * studs;
    cube([width,16,9.6]);
    for (xpos=[ 4 : 8 : width-4 ]){
        translate([xpos,4,1.7]) cylinder(h=9.6,d=4.8);
        translate([xpos,12,1.7]) cylinder(h=9.6,d=4.8);
        }
    
    }
    
    rotate(0) translate([0,-h,0])lego_brick(4);
    rotate(90) translate([0,-h,0])lego_brick(4);
    rotate(180) translate([0,-h,0])lego_brick(4);
    rotate(270) translate([0,-h,h])lego_brick(4);

    /*The goal is to have 4 trackable units
    degrees, x,y,z
    x,y,z increment by lego_brick() size in their respective dimensions.
    degrees are fixed to 0,90,180,270
    
    */

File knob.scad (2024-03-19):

/*
Create Knobs for your rotary Encoders
*/
$fn = 500;

rad=24.0;
//This cylinder covers the hole for the knob
cylinder(3.0,rad,true); //cap thickness, radius
//translate(0.0,0.0,10.0);
difference(){
    cylinder(10,rad,rad);//knob length, top radius ,bot radius
difference(){
    cylinder(d=6.0, h=25);//d inner hole
    translate([0,50.0,40]) //2nd var: how far teh flat is into the hole
    cube(96, center=true);
}
}

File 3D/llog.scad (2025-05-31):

module ll(l = 30 , r = 9){
//Lincon Log module
$fn = 100;
difference(){
difference(){
rotate([0,90,0])cylinder(l,r,r);
translate([5,-r,4]) cube([r,2*r,6]);
 
}
translate([5,-r,-r]) cube([r,2*r,6]);  
}
}
ll(25,8);

//translate([60,0,0])rotate(180)ll(4,8);

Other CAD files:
3D/brick.scad
3D/tests/brick.scad
3D/tests/lego.scad
V2_WIP/3D_prints/knob.scad
V2_WIP/3D_prints/table.scad

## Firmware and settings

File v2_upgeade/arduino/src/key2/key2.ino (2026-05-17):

#include <Encoder.h>
#include <Keyboard.h>
#include <Bounce2.h>
#include <Wire.h>
#include "Adafruit_seesaw.h"
#include <Keyboard.h>

#define SS_SWITCH        24      // this is the pin on the encoder connected to switch
#define SEESAW_BASE_ADDR          0x36  // I2C address, starts with 0x36
const uint8_t Nencoders = 2;
Adafruit_seesaw encoders[Nencoders];

unsigned long btn_press[Nencoders] = {0, 0};
const unsigned long dbd = 200; // deBouce delay = 100 ms
int32_t encoder_positions[] = {0, 0};
bool found_encoders[] = {false, false};
#define color_Btn     1  // g key
#define clear_Btn     2  // c key
#define lift_Btn      3  // l key
#define save_Btn      4  // s key
#define demo_Btn      5  // d key

// Create Bounce objects for buttons
Bounce colorButton = Bounce();
Bounce clearButton = Bounce();
Bounce liftButton  = Bounce();
Bounce saveButton  = Bounce();
Bounce demoButton  = Bounce();
// Variables to track encoder movement direction
int prevEncoder1Position = 0;
int prevEncoder2Position = 0;

void setup() {

  pinMode(0, OUTPUT);
  digitalWrite(0,LOW); // use io as reference.
  Serial.begin(115200);
 // forgot the buttons lol
  pinMode(color_Btn, INPUT_PULLUP);
  pinMode(clear_Btn, INPUT_PULLUP);
  pinMode(lift_Btn,  INPUT_PULLUP);
  pinMode(save_Btn,  INPUT_PULLUP);
  pinMode(demo_Btn,  INPUT_PULLUP);

  colorButton.attach(color_Btn);
  clearButton.attach(clear_Btn);
  liftButton.attach(lift_Btn);
  saveButton.attach(save_Btn);
  demoButton.attach(demo_Btn);

  colorButton.interval(25);
  clearButton.interval(25);
  liftButton.interval(25);
  saveButton.interval(25);
  demoButton.interval(25);
  Wire.begin();
  //while (!Serial) delay(10); // uncomment for serial debug.

bool all_found = true;
for (uint8_t enc = 0; enc < sizeof(found_encoders); enc++) {
  uint8_t addr = SEESAW_BASE_ADDR + enc;

  if (!encoders[enc].begin(addr)) {
    Serial.printf("Couldn't find encoder #%d (0x%02X)\n", enc, addr);
    found_encoders[enc] = false;
    all_found = false;
  } else {
    encoders[enc].pinMode(SS_SWITCH, INPUT_PULLUP);

    // Reset encoder to 0
    encoders[enc].setEncoderPosition(0);
    encoder_positions[enc] = 0;

    //encoders[enc].setGPIOInterrupts((uint32_t)1 << SS_SWITCH, 1);
    encoders[enc].enableEncoderInterrupt();
    found_encoders[enc] = true;
  }
}
  if (all_found) {
    Serial.print("All encoders found at addresses: ");
    for (uint8_t enc = 0; enc < sizeof(found_encoders); enc++) {
      Serial.printf("0x%02X ", SEESAW_BASE_ADDR + enc);
    }
    Serial.println();
  }
}

void loop() {
//unsigned long now = millis(); 
  for (uint8_t enc=0; enc<sizeof(found_encoders); enc++) {
     if (found_encoders[enc] == false) continue;

     int32_t new_position = encoders[enc].getEncoderPosition();
     // did we move around?
     if (encoder_positions[enc] != new_position) {
      encoder_positions[enc] = new_position; // update position before printing
    // Serial.printf("X: %ld, Y: %ld \n", encoder_positions[0],encoder_positions[1]);            

  int encoder1Position = encoder_positions[0];
  int encoder2Position = encoder_positions[1];
    // Detect encoder 1 movement direction
  int encoder1Direction = 0;
  if (encoder1Position > prevEncoder1Position) {
      encoder1Direction = 1; // Positive direction
  } else if (encoder1Position < prevEncoder1Position) {
      encoder1Direction = -1; // Negative direction
  }

  // Detect encoder 2 movement direction
  int encoder2Direction = 0;
  if (encoder2Position > prevEncoder2Position) {
      encoder2Direction = 1; // Positive direction
      } else if (encoder2Position < prevEncoder2Position) {
           encoder2Direction = -1; // Negative direction
        }

  prevEncoder1Position = encoder1Position;
  prevEncoder2Position = encoder2Position;

  // Use encoder direction variables to perform actions
  if (encoder1Direction == -1) {
   // Serial.println("LEFT");
    Keyboard.press(KEY_LEFT_ARROW);
    Keyboard.release(KEY_LEFT_ARROW);
  } else if (encoder1Direction == 1) {
    // Serial.println("RiGHT");
    Keyboard.press(KEY_RIGHT_ARROW);
    Keyboard.release(KEY_RIGHT_ARROW);
  } else {
    Keyboard.release(KEY_RIGHT_ARROW);
    Keyboard.release(KEY_LEFT_ARROW);
  }

  if (encoder2Direction == 1) {
    Serial.println("UP");
    Keyboard.press(KEY_UP_ARROW);
    Keyboard.release(KEY_UP_ARROW);
  } else if (encoder2Direction == -1) {
    Serial.println("DOWN");
    Keyboard.press(KEY_DOWN_ARROW);
    Keyboard.release(KEY_DOWN_ARROW);
  } else {
    Keyboard.release(KEY_DOWN_ARROW);
    Keyboard.release(KEY_UP_ARROW);
  }
     
  }
    // Handle button presses with debouncing
  colorButton.update();
  if (colorButton.fell()) {
    Serial.println("Color Change");
    Keyboard.press(KEY_G);
    Keyboard.release(KEY_G);
    }
  
  clearButton.update();
  if (clearButton.fell()) {  
    Serial.println("CLEAR");
    Keyboard.press(KEY_C);
    Keyboard.release(KEY_C);
    }
  
  liftButton.update();
  if (liftButton.fell()) {  
    Serial.println("LIFT");
    Keyboard.press(KEY_L);
    Keyboard.release(KEY_L);
    }
  saveButton.update();
  if (saveButton.fell()) {
    Serial.println("Saving file");
    Keyboard.press(KEY_S);
    Keyboard.release(KEY_S);
    delay(5000); //Really want to prevent spamming this one.
    Serial.println("Saving Complete"); 
    } 

  demoButton.update();
  if (demoButton.fell()) {
    Serial.println("DEMOLITION");
    Keyboard.press(KEY_D);
    Keyboard.release(KEY_D);
    }
  }  
  delay(10);
}

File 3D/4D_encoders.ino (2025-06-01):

#include <Wire.h>
#include "Adafruit_seesaw.h"
#include <Keyboard.h>

/*Tenative idea is to have X,Y,Z, and view select*/
/* 
  swapped to a teensy 4.0 cuz is teensier
  also the hardware check thing was cool, but not practical where Im still prototyping
 */
#define SS_SWITCH        24      // this is the pin on the encoder connected to switch
#define SEESAW_BASE_ADDR          0x36  // I2C address, starts with 0x36
const uint8_t Nencoders = 5;

Adafruit_seesaw encoders[Nencoders];
bool found_encoders[Nencoders] = {false};
int32_t encoder_positions[Nencoders] = {0};
unsigned long btn_press[Nencoders] = {0};
const unsigned long dbd = 200;

void setup() {
  Serial.begin(115200);
  Wire.begin();
  while (!Serial) delay(5);

//bool all_found = true;
//for (uint8_t enc = 0; enc < sizeof(found_encoders); enc++) {
for (uint8_t enc = 0; enc < Nencoders; enc++) {
  uint8_t addr = SEESAW_BASE_ADDR + enc;

  if (!encoders[enc].begin(addr)) {
    //I wasnt carfull when rebuilding the controler, to put contiguous addresses in. and I dont want to hear about address not found RN
    //Serial.printf("Couldn't find encoder #%d (0x%02X)\n", enc, addr);
    found_encoders[enc] = false;
    //all_found = false;
  } else {
    encoders[enc].pinMode(SS_SWITCH, INPUT_PULLUP);

    // Reset encoder to 0
    encoders[enc].setEncoderPosition(0);
    encoder_positions[enc] = 0;

    encoders[enc].setGPIOInterrupts((uint32_t)1 << SS_SWITCH, 1);
    encoders[enc].enableEncoderInterrupt();
    found_encoders[enc] = true;
  }
}
//  if (all_found) {
    Serial.print("encoders found at addresses: ");
    //for (uint8_t enc = 0; enc < sizeof(found_encoders); enc++) {
      for (uint8_t enc = 0; enc < Nencoders; enc++) {
        if(found_encoders[enc]){
      Serial.printf("0x%02X ", SEESAW_BASE_ADDR + enc);
      }   
    }
    Serial.println();
  }

void cls(){
  for (uint8_t enc = 0; enc < Nencoders; enc++) {
  encoders[enc].setEncoderPosition(0);
  }
  }

void loop() {

if(Serial.available()){
  char c = Serial.read();
  if(c == 'c'){
    cls();
    }
  }

unsigned long now = millis(); 
  for (uint8_t enc=0; enc<sizeof(found_encoders); enc++) {
     if (found_encoders[enc] == false) continue;

     int32_t new_position = encoders[enc].getEncoderPosition();
     // did we move around?
     if (encoder_positions[enc] != new_position) {
      encoder_positions[enc] = new_position; // update position before printing
      //Serial.printf("X: %ld, Y: %ld, Z: %ld, E4: %ld\n", encoder_positions[0],encoder_positions[1],encoder_positions[2],encoder_positions[3]);
      //Serial.printf("X: %ld, Y: %ld, Z: %ld, R: %ld, V: %ld \n", encoder_positions[0],encoder_positions[1],encoder_positions[2],encoder_positions[3],encoder_positions[4]); 
      Serial.printf("X: %ld, Y: %ld, Z: %ld, R: %ld\n", encoder_positions[0],encoder_positions[1],encoder_positions[2],encoder_positions[3]);            
     }

     if (! encoders[enc].digitalRead(SS_SWITCH)){
        if(now - btn_press[enc] > dbd){        
        Serial.printf("E#%d pressed\n",enc);
        Serial.flush(); //teensy serial is too fast. wait for the print statment then set debounce time
        btn_press[enc] = now;
     }
     }
  }


  // don't overwhelm serial port
  yield(); //delay calls yield
  delay(10);
}

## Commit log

2024-02-23 Update demo.py
    added a gear primitive
2024-02-26 Update demo.py
    treating demo as a module.
    gear function inner circle y offset is wrong.
    [demo.py]
2024-03-19 Add files via upload
    This is the OpenScad file I used to create knobs for the Sketch-Y-Etch, scaled to the encoder knobs I have. Your knobs may vary.
    [knob.scad]
2024-03-19 Update keys.ino
    Added IO Debounce on Buttons.
2025-04-01 include encoder for reference
2025-04-05 encoder e2 update.
2025-04-28 more organizing
    [knob.scad, knob.stl, table.scad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]
2025-05-25 A control interface using a teensy 4.1 and seesaw encoders
2025-05-25 print val not mem lol
2025-05-26 Todo: make adding more encoders easier
2025-05-29 semifuntional
    lego.scadis output file.
    brick.scad is the model
    test6.py is a plot on E#3 button press
    some of the dimensions increments might be subject to improvement
    maybe we'll draw with a 2x2 brick or a 2x4 brick or maybe 2x1 not sure yet
    [brick.scad, lego.scad]
2025-05-31 draft lincoln log model
    [llog.scad]
2026-04-21 This is the model referenced in the test code
    [brick.scad]
2026-05-16 Add key2.ino for encoder and button handling
2026-05-17 Implement button handling and serial logging
    Added button press handling and serial output for actions.
